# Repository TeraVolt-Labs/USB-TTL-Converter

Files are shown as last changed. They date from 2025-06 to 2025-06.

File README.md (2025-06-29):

# USB to TTL Converter — FT231XQ-R

A compact, reliable, and versatile **USB to UART** converter designed with the **FT231XQ-R** chipset. This open hardware project features dual voltage operation, UART activity LEDs, and dual JST-GH connectors to support a wide range of embedded development and debugging workflows.

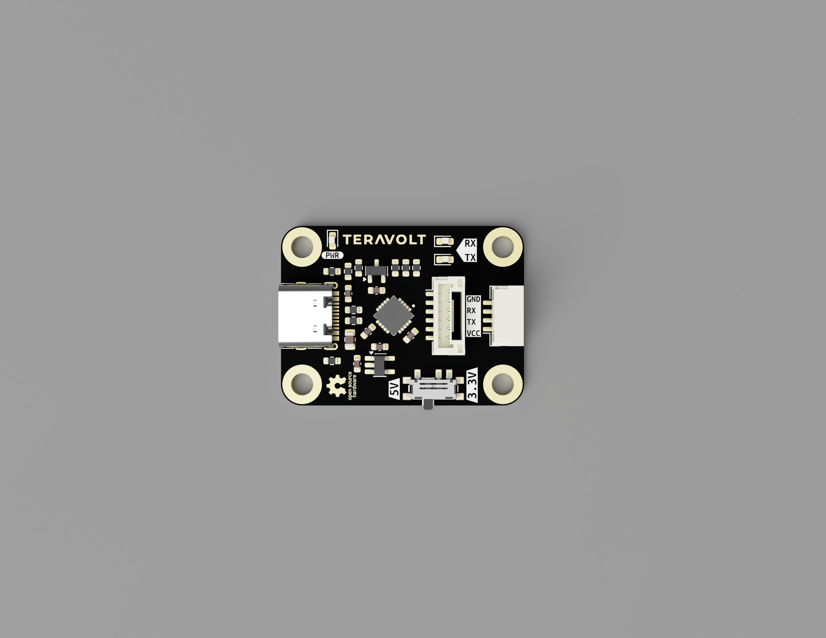
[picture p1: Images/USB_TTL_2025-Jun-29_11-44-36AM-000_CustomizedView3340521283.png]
USB to TTL Converter Banner


---

## Features

- ✅ Based on **FTDI FT231XQ-R** (USB to UART bridge)
- ✅ **USB Type-C** connector for modern compatibility
- ✅ Selectable I/O voltage: **3.3V / 5V** via slider switch
- ✅ **TX/RX activity LEDs** for visual communication debug
- ✅ **Power LED** indicator
- ✅ Two **JST-GH** connectors:
  - **4-pin**: VCC, TX, RX, GND
  - **6-pin**: RST, RX, TX, VCC, CTS, GND
- ✅ Compact and easy to integrate
- 🔒 **Non-commercial Open Hardware License**

---

## 🔧 Specifications

| Parameter | Details |
|---|---|
| USB Interface | USB Type-C |
| USB-UART Chip | FT231XQ-R |
| Logic Level | Selectable 3.3V or 5V |
| Status Indicators | TX, RX, Power (LEDs) |
| Connectors | JST-GH 4-pin & 6-pin |
| UART Signals | TX, RX, CTS, RST |
| Board Size | ~35mm × 25mm |

---

## Pinouts

### 4-Pin JST-GH Connector

| Pin | Function | Description |
|-----|---|---|
| 1 | VCC | Selected voltage (3.3V/5V) |
| 2 | TX | UART Transmit (from USB) |
| 3 | RX | UART Receive (to USB) |
| 4 | GND | Ground |

### 6-Pin JST-GH Connector

| Pin | Function | Description |
|-----|---|---|
| 1 | RST | Reset (active low) |
| 2 | RX | UART Receive |
| 3 | TX | UART Transmit |
| 4 | VCC | 3.3V or 5V (selected) |
| 5 | CTS | Clear to Send |
| 6 | GND | Ground |

---

## Driver Installation

### Windows

1. Download the VCP driver from: [https://ftdichip.com/drivers/](https://ftdichip.com/drivers/)
2. Install and plug in the device
3. COM port will appear in **Device Manager**

### macOS

- No driver required for modern versions
- Optional FTDI VCP driver available on FTDI website

### Linux

- Plug-and-play with most distributions
- Check with `dmesg | grep ttyUSB`

---

## License

**Custom Non-Commercial Open Hardware License**

> You are free to use, modify, reproduce, and distribute this hardware **for non-commercial purposes only**, provided that you give **proper credit** and include a copy of the license.

Full terms in [`LICENSE.txt`](./Licence.txt)

---

## Credits

Designed and developed by [TeraVolt Labs](https://www.linkedin.com/company/teravoltlabs)  
Powered by **FTDI FT231XQ-R**

---

## Support & Contributions

This is an open hardware project. Feel free to open issues, suggest improvements, or fork and build your own versions (non-commercially).

---

## Documentation
Official Documentation can be found at: [GitBook](https://teravolt.gitbook.io/teravolt/peripherals/usb-to-ttl-converter)

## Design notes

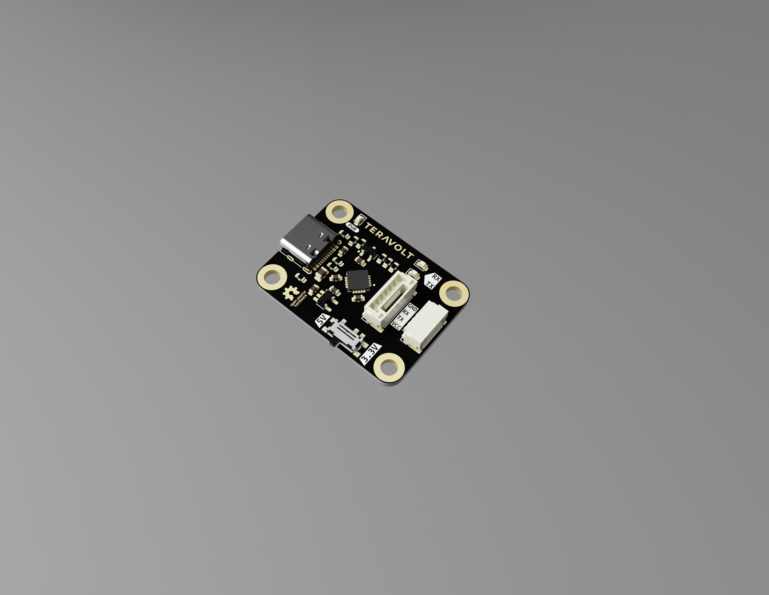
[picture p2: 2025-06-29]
Images/USB_TTL_2025-Jun-29_11-45-25AM-000_CustomizedView4288134034.png

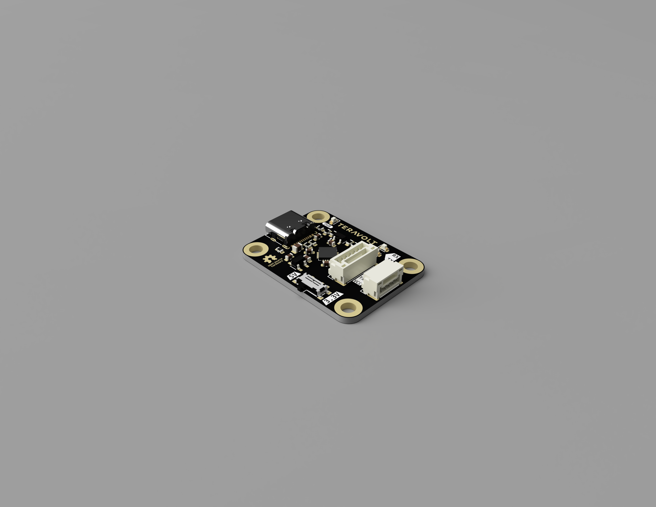
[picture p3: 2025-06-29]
Images/USB_TTL_2025-Jun-29_11-47-35AM-000_CustomizedView11205967025.png

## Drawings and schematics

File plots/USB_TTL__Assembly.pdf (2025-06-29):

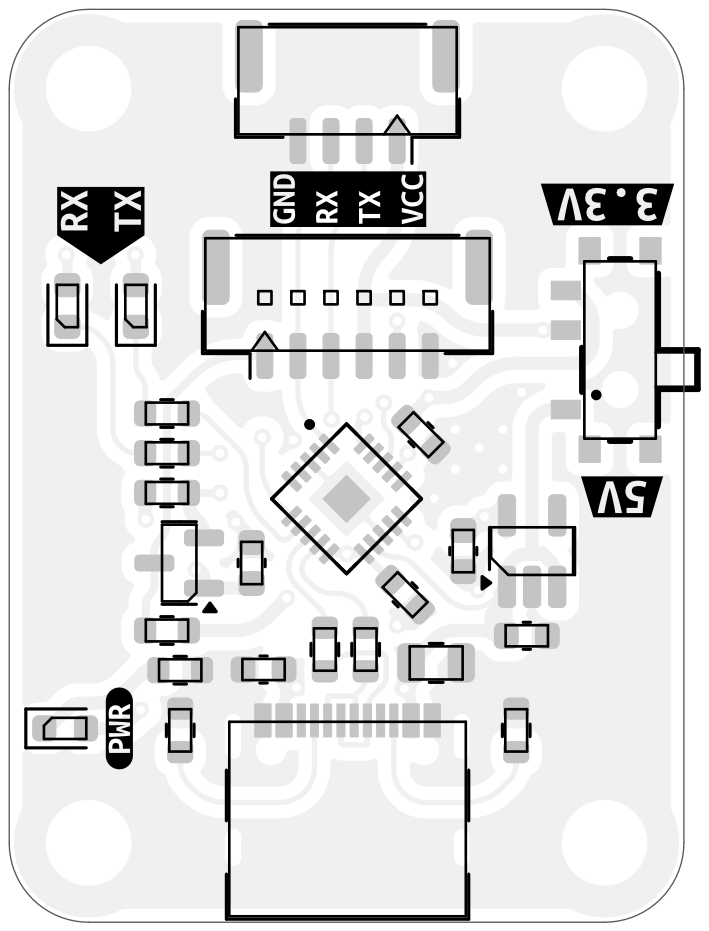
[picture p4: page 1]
D Date: KiCad; E.D.A. 9.0.1 Size: A4; Rev:; Id: /1 Title: File: USB_TTL.kicad_pcb Sheet: Black; And; White; TOP; Board2Pdf:; Black; TOP -; Page

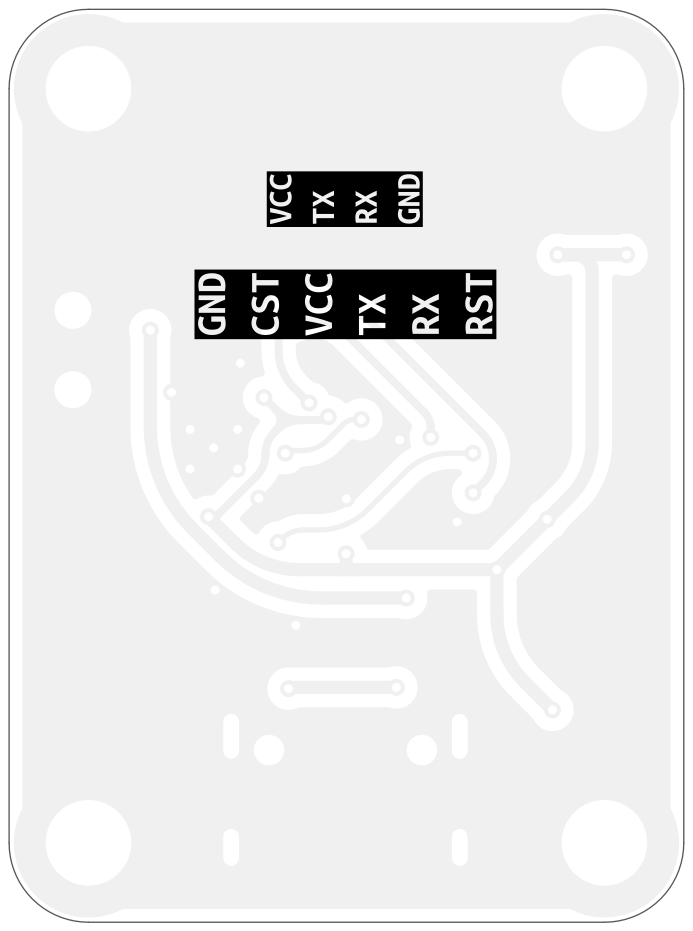
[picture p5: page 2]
D Date: KiCad; E.D.A. 9.0.1 Size: A4; Rev:; Id: /1 Title: File: USB_TTL.kicad_pcb Sheet: Black; And; White; BOT Board2Pdf:; Black; BOT -; Page 2/2

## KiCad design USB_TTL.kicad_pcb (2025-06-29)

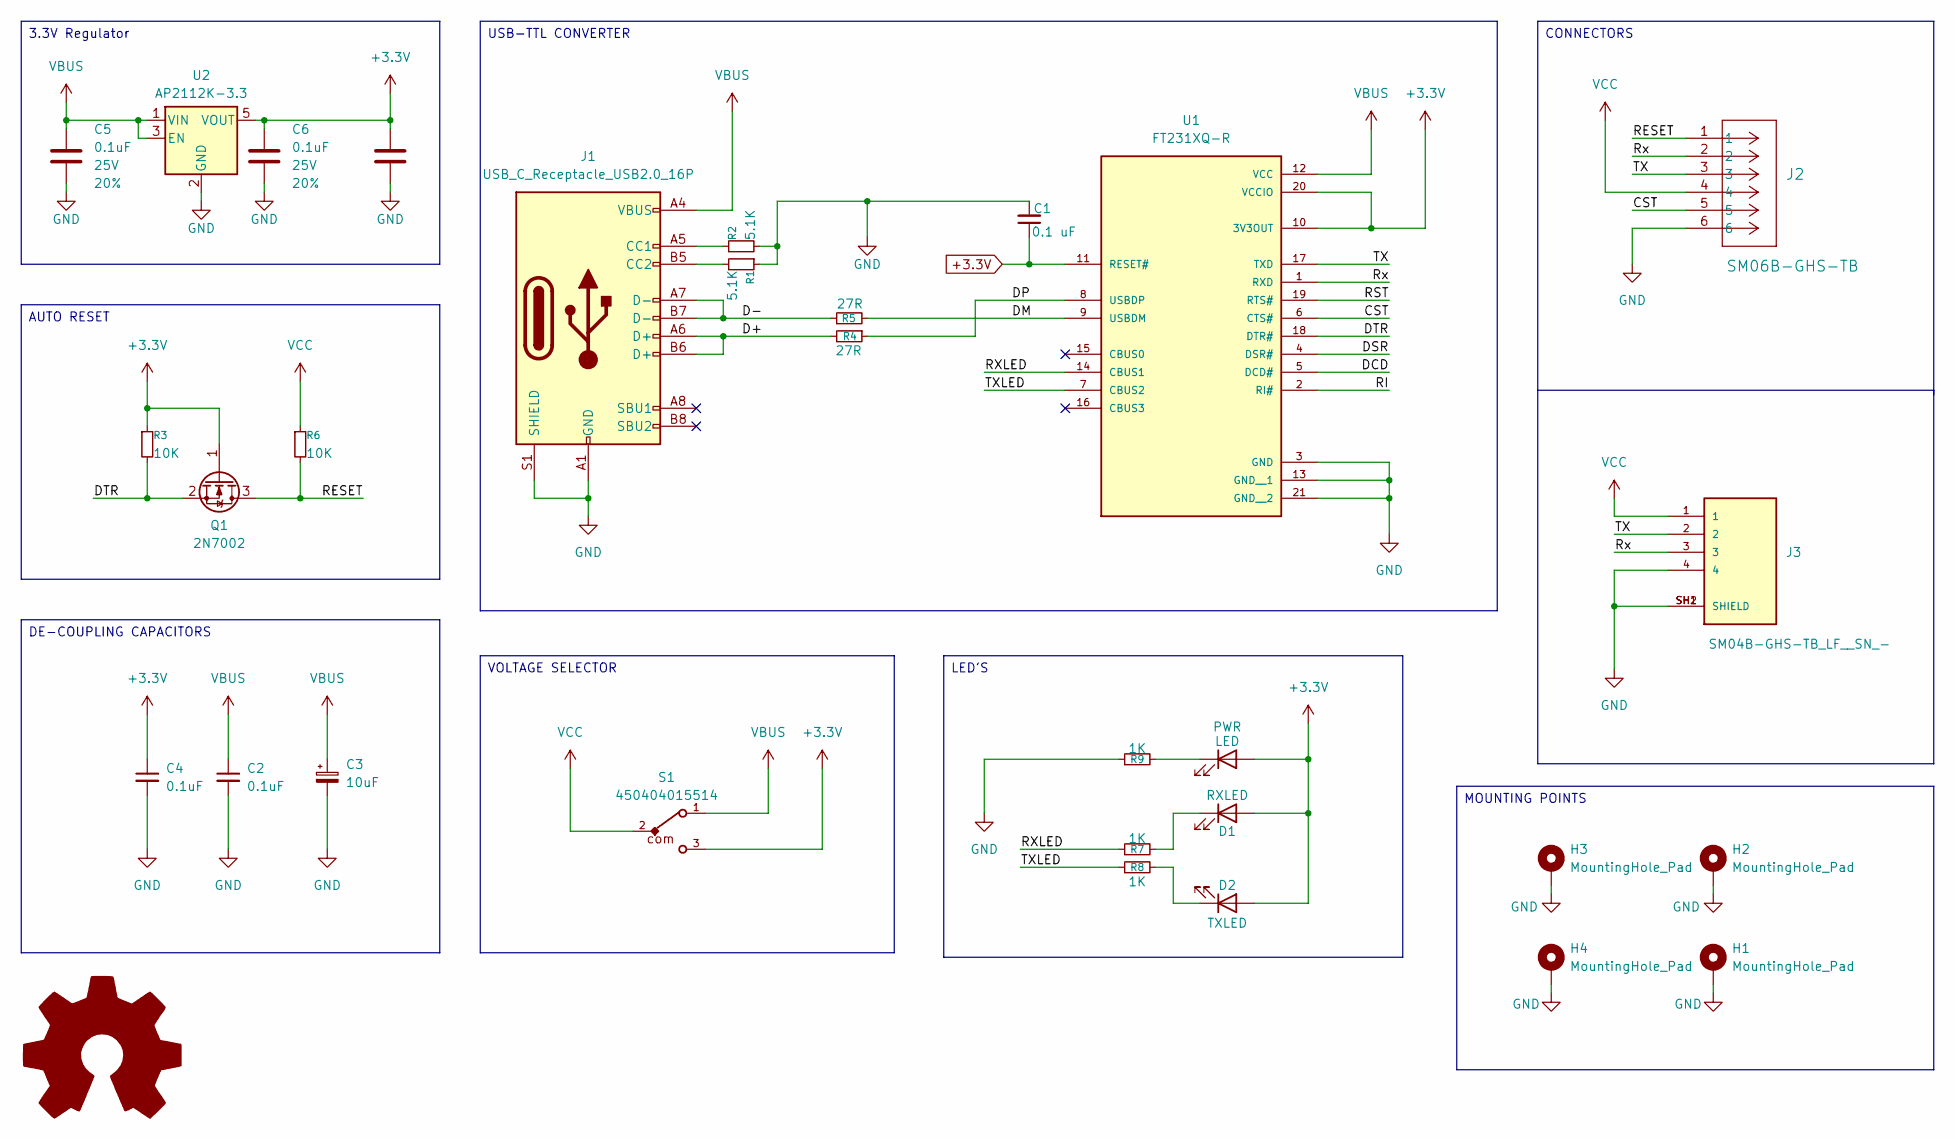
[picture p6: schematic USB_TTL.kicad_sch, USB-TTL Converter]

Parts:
C1: 0.1 uF; C_0603_1608Metric
C2, C4: 0.1uF; C_0603_1608Metric
C3: 10uF; C_0805_2012Metric
C5, C6: 0.1uF; C_0603_1608Metric; Voltage 25V; Tolerance 20%
C7: 1.0uF; C_0603_1608Metric; Voltage 16V; Tolerance 10%
D1: RXLED; LED_0603_1608Metric
D2: TXLED; LED_0603_1608Metric
H1, H2, H3, H4: MountingHole_Pad; MountingHole_3.2mm_M3_DIN965_Pad
J1: USB_C_Receptacle_USB2.0_16P; USB_C_Receptacle_G-Switch_GT-USB-7010ASV
J2: SM06B-GHS-TB; JST_GH_BM06B-GHS-TBT_1x06-1MP_P1.25mm_Vertical
J3: SM04B-GHS-TB_LF__SN_-; JST_GH_SM04B-GHS-TB_1x04-1MP_P1.25mm_Horizontal; PARTREV NA
PWR: LED; LED_0603_1608Metric
Q1: 2N7002; SOT-23
R1, R2: 5.1K; R_0603_1608Metric
R3, R6: 10K; R_0603_1608Metric
R4, R5: 27R; R_0603_1608Metric
R7, R8, R9: 1K; R_0603_1608Metric
S1: 450404015514
U1: FT231XQ-R; QFN50P400X400X80-21N; PARTREV 1.2
U2: AP2112K-3.3; SOT-23-5_HandSoldering

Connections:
+3.3V: C1.1, C4.1, C6.1, C7.1, D1.2 (A), D2.2 (A), Q1.1 (G), R3.1, S1.3, U1.10 (3V3OUT), U1.11 (RESET#), U1.20 (VCCIO), U2.5 (VOUT); also elsewhere on the board
/CST: J2.5, U1.6 (CTS#)
/D+: J1.A6 (D+), J1.B6 (D+), R4.2
/D-: J1.A7 (D-), J1.B7 (D-), R5.1
/DCD: U1.5 (DCD#)
/DM: R5.2, U1.9 (USBDM)
/DP: R4.1, U1.8 (USBDP)
/DSR: U1.4 (DSR#)
/DTR: Q1.2 (S), R3.2, U1.18 (DTR#)
/RESET: J2.1, Q1.3 (D), R6.2
/RI: U1.2 (RI#)
/RST: U1.19 (RTS#)
/RXLED: R7.1, U1.14 (CBUS1)
/Rx: J2.2, J3.3, U1.1 (RXD)
/TX: J2.3, J3.2, U1.17 (TXD)
/TXLED: R8.1, U1.7 (CBUS2)
GND: C1.2, C2.2, C3.2, C4.2, C5.2, C6.2, C7.2, H1.1, H2.1, H3.1, H4.1, J1.A1 (GND), J1.A12 (GND), J1.B1 (GND), J1.B12 (GND), J1.S1 (SHIELD), J2.6, J3.4, J3.SH1 (SHIELD), J3.SH2 (SHIELD), R1.1, R2.2, R9.1, U1.3 (GND), U1.13 (GND__1), U1.21 (GND__2), U2.2 (GND)
unnamed: D1.1 (K), R7.2
unnamed: D2.1 (K), R8.2
unnamed 19: PWR.1 (K), R9.2; also elsewhere on the board
unnamed: J1.A5 (CC1), R2.1
unnamed: J1.B5 (CC2), R1.2
VBUS: C2.1, C3.1, C5.1, J1.A4 (VBUS), J1.A9 (VBUS), J1.B4 (VBUS), J1.B9 (VBUS), S1.1, U1.12 (VCC), U2.1 (VIN), U2.3 (EN)
VCC: J2.4, J3.1, R6.1, S1.2

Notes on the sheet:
AUTO RESET
USB-TTL CONVERTER
MOUNTING POINTS
LED'S
DE-COUPLING CAPACITORS
3.3V Regulator
CONNECTORS
VOLTAGE SELECTOR

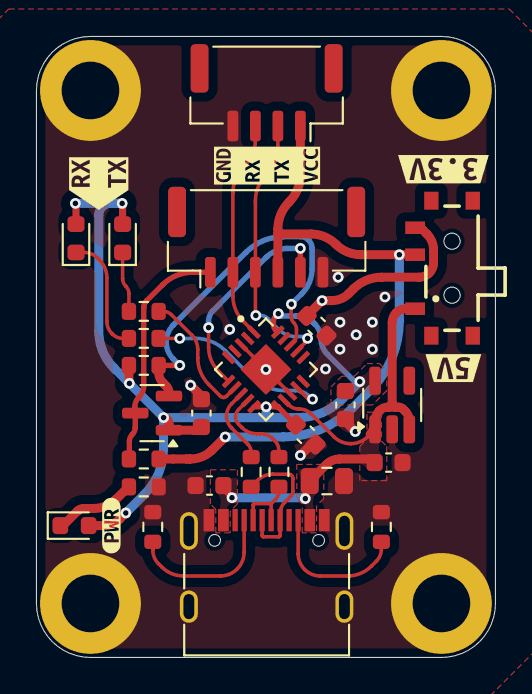
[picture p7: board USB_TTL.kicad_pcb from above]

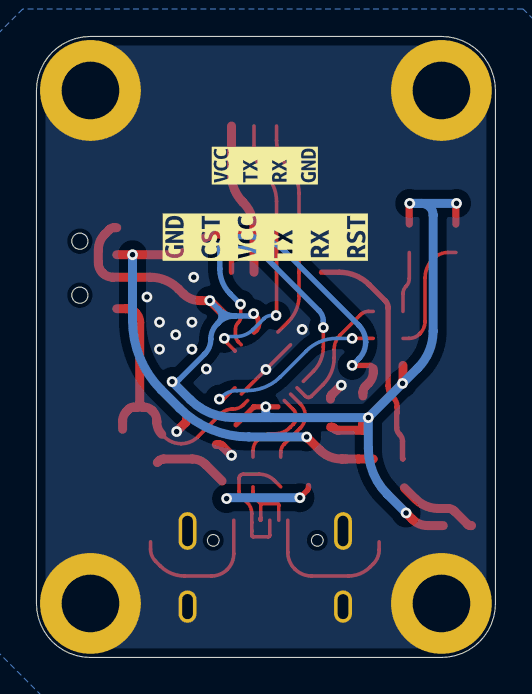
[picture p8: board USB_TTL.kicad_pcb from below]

Board: 2 copper layers, 25.5 x 34.5 mm, 37 parts (2 on the bottom side), 20 nets.

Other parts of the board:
D3: LED; LED_0603_1608Metric
kibuzzard-686110B6: G***; kibuzzard-686110B6
kibuzzard-686117B9: G***; kibuzzard-686117B9
kibuzzard-686117ED: G***; kibuzzard-686117ED
kibuzzard-68611096: G***; kibuzzard-68611096
kibuzzard-68611453: G***; kibuzzard-68611453
kibuzzard-68611696: G***; kibuzzard-68611696
kibuzzard-68611715: G***; kibuzzard-68611715

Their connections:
+3.3V: D3.2 (A); also elsewhere on the board
unnamed 19: D3.1 (K); also elsewhere on the board
